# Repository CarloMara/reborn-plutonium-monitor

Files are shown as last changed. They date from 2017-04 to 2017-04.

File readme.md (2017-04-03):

**Introduction**

Reborn Plutoniom Monitor is a small project born from the idea of having the possibility to carry a second monitor around. FYI I'm a student and I move around the city a lot. There are other option in the market that could suit my needs, but they are mostly based off USB, which I imagine would be a pain to get working on linux.

The project is based off a 14 inch laptop display that can be easly found on common on-line stores as spare.

*Things done so far*

I've just designed a first test board with all of the connections from the display's flat cable broken out, so it should be a little easier to test whether or not the pinout of the panel is correct. 

-----------------------------------------------------------------------------------------------------------------------------------------------------------

**Brief Display Info**

The display I have choose it's not very new, but thanks to it's age a datasheet for it is easily repairable.

I've also chosen this display because it's has all the back-lighting control electronic integrated, saving a big hassle. 

----------------------------------------------------------------------------------------------------------------------------------------------------------

**Possible Development Path**

I have bought all the components needed to build the test board , but I still need to find some time to etch a pcb, and try it out.

In the future I plan to make a bigger board, maybe with a 4.0 ble chip in order to control the brightness and get the battery status to the host pc.

Of course this means designing a solution to charge the battery, maybe using USB-PD, but right now I don't have any time for that.

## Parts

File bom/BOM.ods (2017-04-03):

 |  | BOM of Reborn Plutonium Monitor
QTY | PART/PACK | €/PACK | €/PART | URL | INFO | QTY TO BUY | COST | PN – TME | PN- DIGY
1 | 1 | 41 | 41 | http://www.ebay.it/itm/COMPATIBLE-LP140WF1-SP-U1-LCD-LAPTOP-SCREEN-14-0-LG-PHILIPS-PANEL-UK-SHIPP-/380973772351 | LCD panel | 1 | 41
1 | 10 | 6.5 | 0.65 | http://www.ebay.com/itm/10pcs-30-Pin-0-5mm-Pitch-300mm-Power-Ribbon-FFC-Flexible-Flat-Cable-Forward/191950130486 | Flex Ribbon Cable | 1 | 6.5
1 | 1 | 1.59 | 1.59 | http://www.tme.eu/en/details/2040210-1/euro-hdmi-connectors/te-connectivity/ | DP Socket | 1 | 1.59 | 2040210-1
1 | 1 | 0.85 | 0.85 | http://www.tme.eu/en/details/f0500wr-s-30pt/connectors-ffc-fpc-05mm/joint-tech/ | FFC Connector | 1 | 0.85 | F0500WR-S-30PT
1 | 1 | 2.9 | 2.9 | http://www.tme.eu/en/details/mx-98266-0317/ffc-fpc-ribbon-cables/molex/982660317/ | FFC cable | 1 | 2.9 | MX-98266-0317
 |  |  |  |  |  |  |  | TOTAL COST
 |  |  |  |  |  |  |  | € 52.84

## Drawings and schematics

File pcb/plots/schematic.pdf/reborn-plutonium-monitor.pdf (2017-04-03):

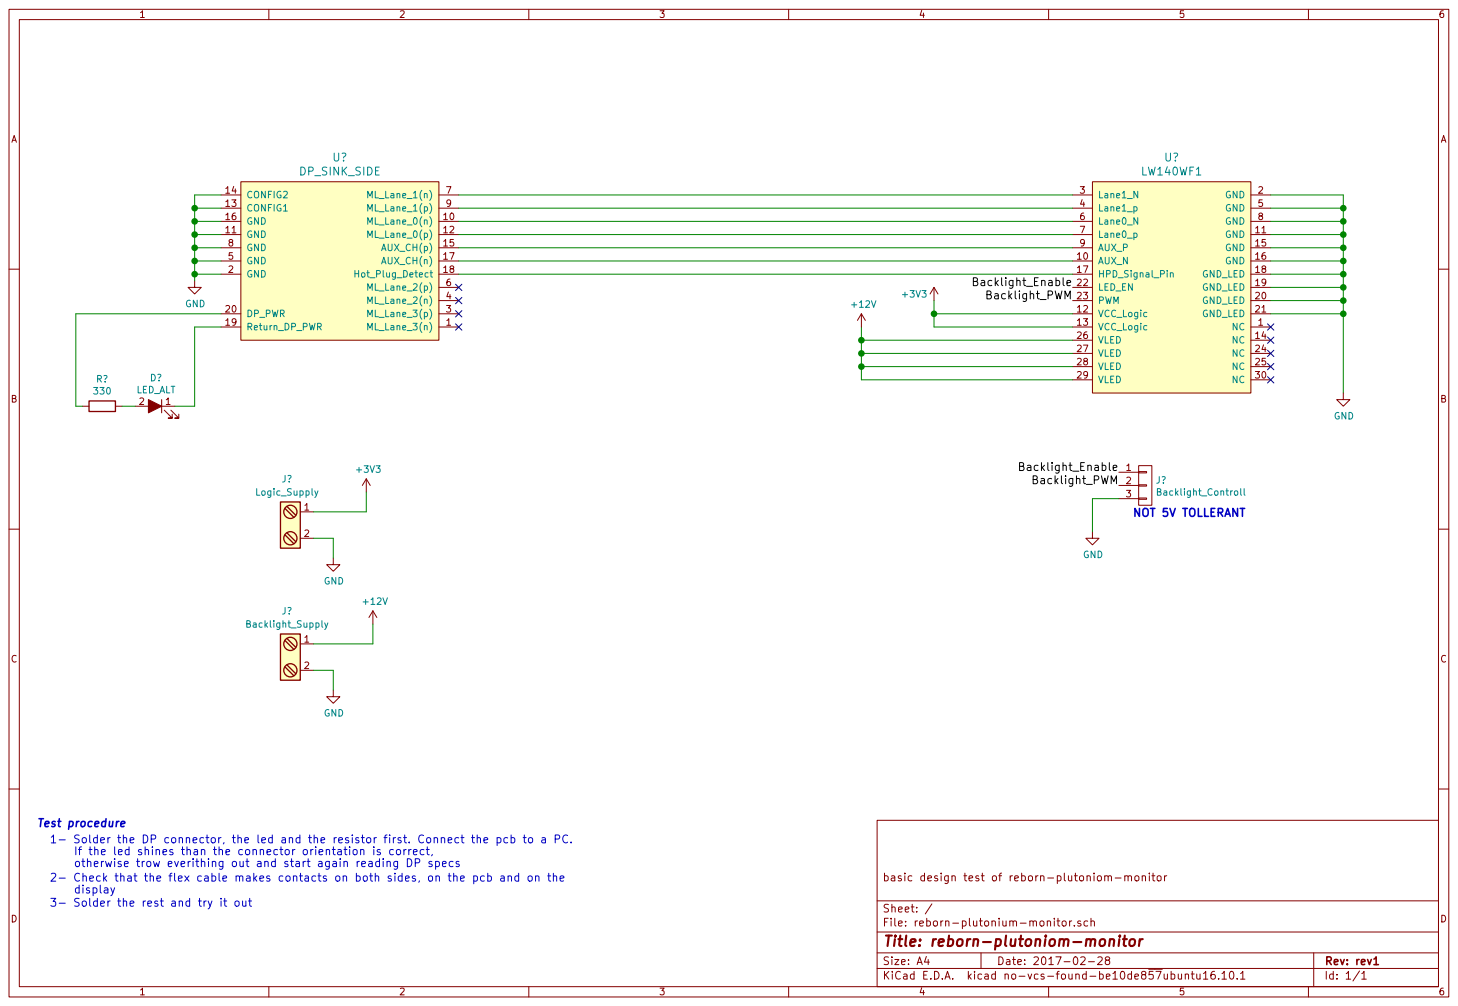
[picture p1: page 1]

1- Solder the DP connector, the led and the resistor first. Connect the pcb to a PC.
If the led shines than the connector orientation is correct,
otherwise trow everithing out and start again reading DP specs
2- Check that the flex cable makes contacts on both sides, on the pcb and on the
display

File: reborn-plutonium-monitor.sch Sheet: / basic design test of reborn-plutoniom-monitor

Id: 1/1 Title: reborn-plutoniom-monitor

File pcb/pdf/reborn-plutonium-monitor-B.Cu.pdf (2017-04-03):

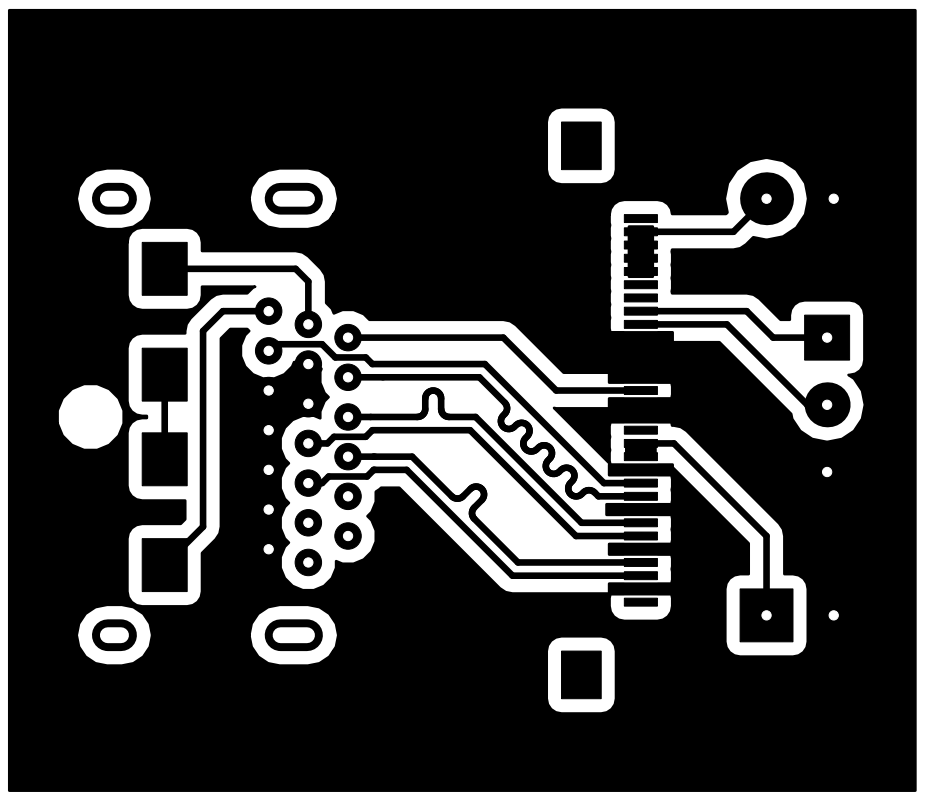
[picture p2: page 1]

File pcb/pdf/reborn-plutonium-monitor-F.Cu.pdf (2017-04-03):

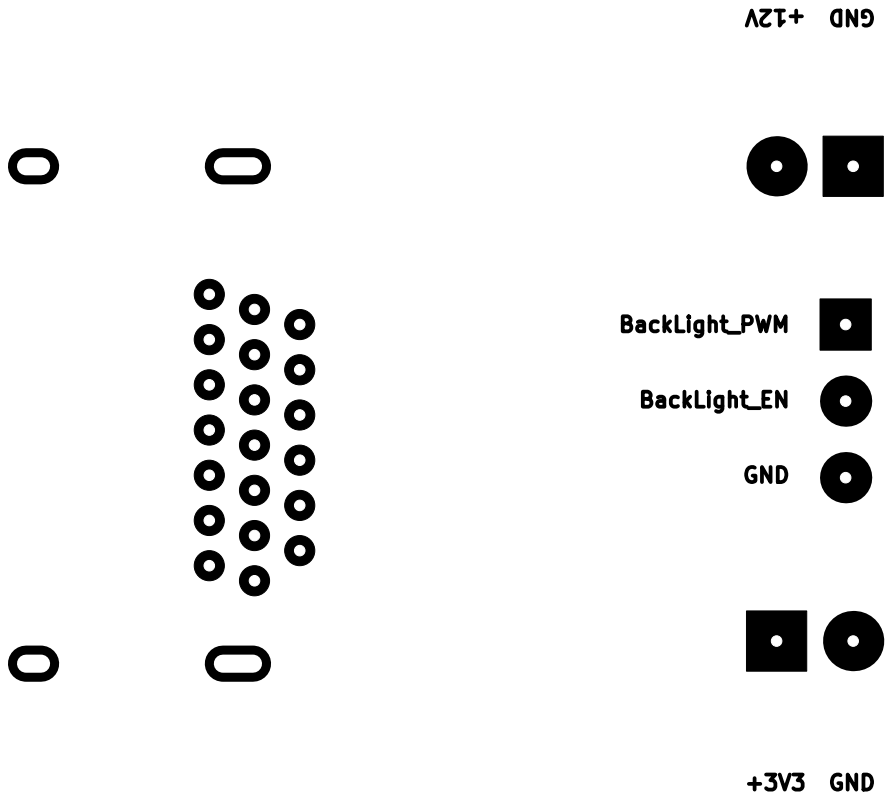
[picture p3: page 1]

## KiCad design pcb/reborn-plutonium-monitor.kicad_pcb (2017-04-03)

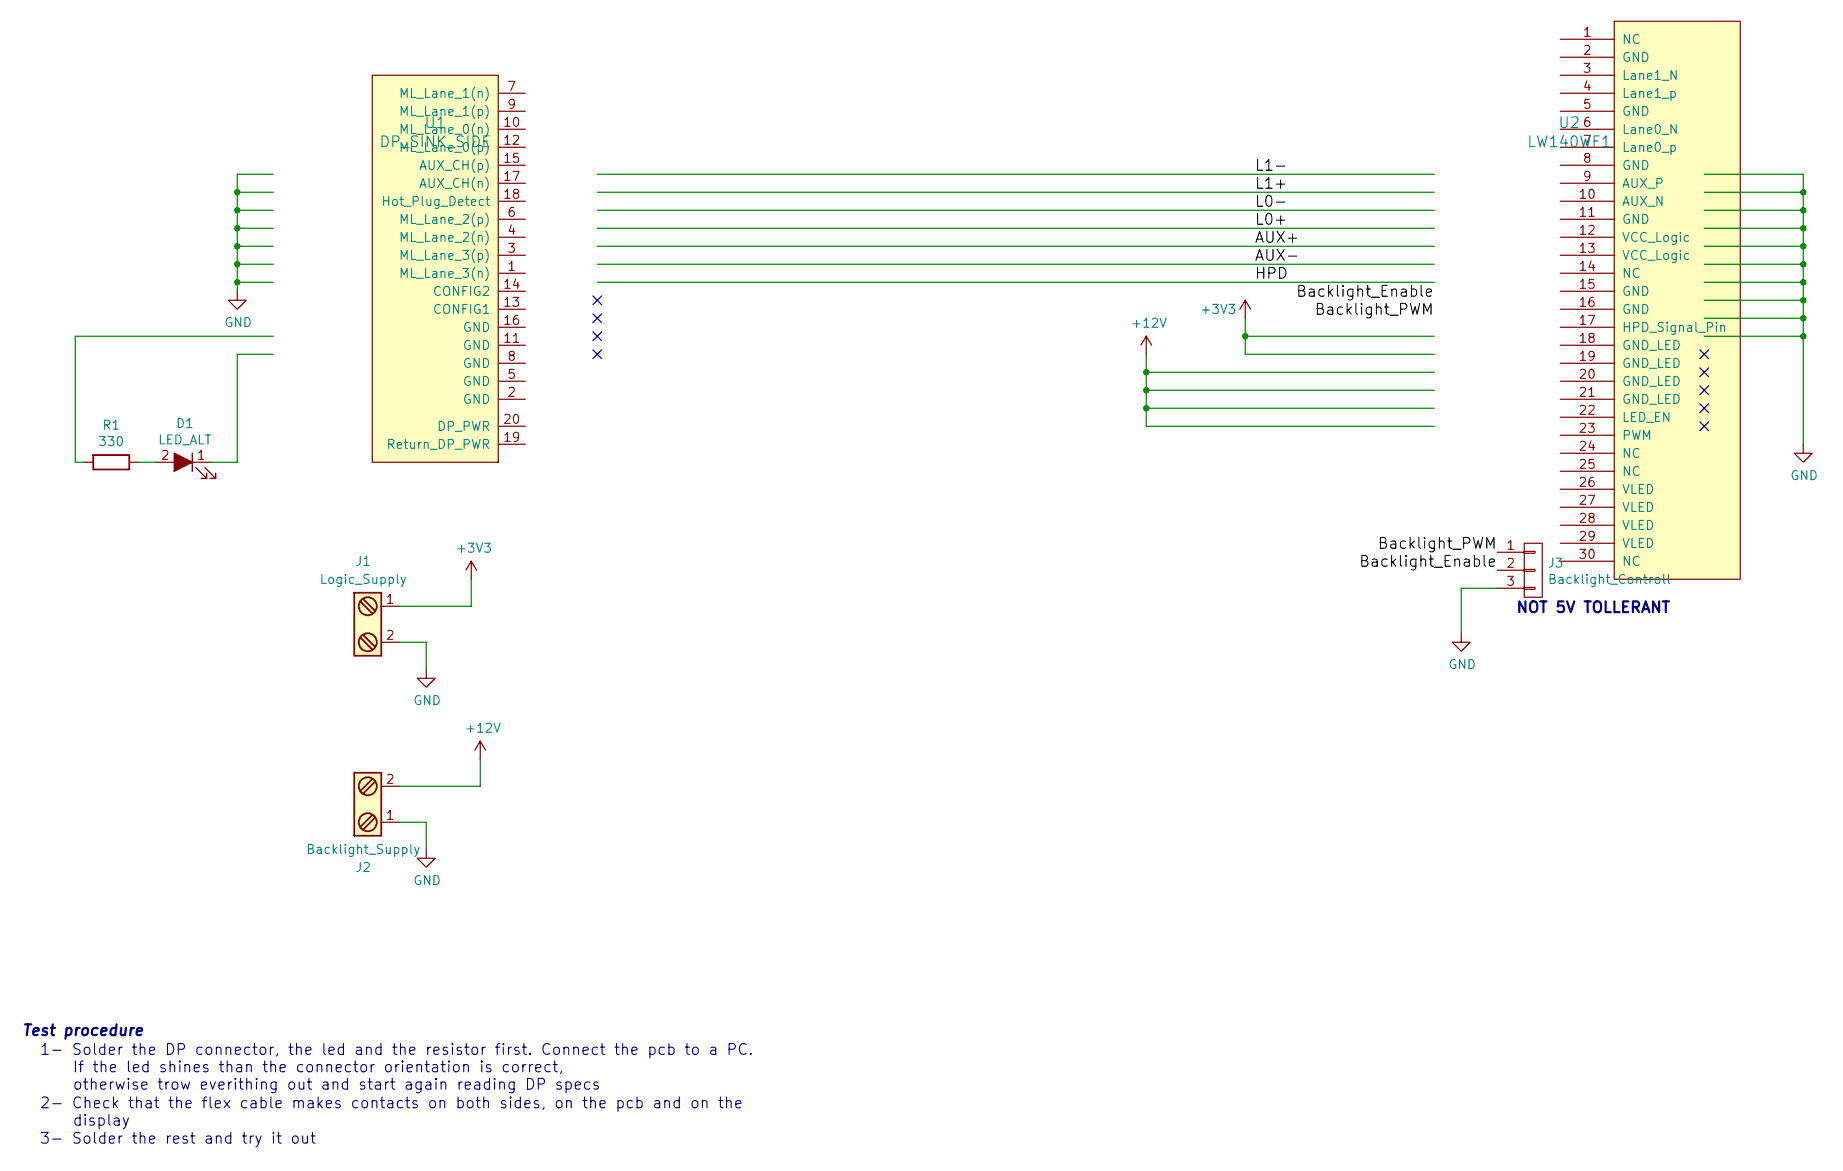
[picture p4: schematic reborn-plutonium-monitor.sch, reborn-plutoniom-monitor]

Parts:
D1: LED_ALT; R_1206_HandSoldering
J1: Logic_Supply; TerminalBlock_Pheonix_MPT-2.54mm_2pol
J2: Backlight_Supply; TerminalBlock_Pheonix_MPT-2.54mm_2pol
J3: Backlight_Controll; Pin_Header_Straight_1x03_Pitch2.54mm
R1: 330; R_1206_HandSoldering
U1: DP_SINK_SIDE; 2040210-1
U2: LW140WF1; F0500WR-S-30PT

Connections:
+3V3: J1.1, U2.12 (VCC_Logic), U2.13 (VCC_Logic)
+12V: J2.2, U2.26 (VLED), U2.27 (VLED), U2.28 (VLED), U2.29 (VLED)
/AUX+: U1.15 (AUX_CH(p)), U2.9 (AUX_P)
/AUX-: U1.17 (AUX_CH(n)), U2.10 (AUX_N)
/Backlight_Enable: J3.2, U2.22 (LED_EN)
/Backlight_PWM: J3.1, U2.23 (PWM)
/HPD: U1.18 (Hot_Plug_Detect), U2.17 (HPD_Signal_Pin)
/L0+: U1.12 (ML_Lane_0(p)), U2.7 (Lane0_p)
/L0-: U1.10 (ML_Lane_0(n)), U2.6 (Lane0_N)
/L1+: U1.9 (ML_Lane_1(p)), U2.4 (Lane1_p)
/L1-: U1.7 (ML_Lane_1(n)), U2.3 (Lane1_N)
GND: J1.2, J2.1, J3.3, U1.2 (GND), U1.5 (GND), U1.8 (GND), U1.11 (GND), U1.13 (CONFIG1), U1.14 (CONFIG2), U1.16 (GND), U2.2 (GND), U2.5 (GND), U2.8 (GND), U2.11 (GND), U2.15 (GND), U2.16 (GND), U2.18 (GND_LED), U2.19 (GND_LED), U2.20 (GND_LED), U2.21 (GND_LED)
unnamed: D1.1 (K), U1.19 (Return_DP_PWR)
unnamed: D1.2 (A), R1.1
unnamed: R1.2, U1.20 (DP_PWR)

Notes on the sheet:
Test procedure
1- Solder the DP connector, the led and the resistor first. Connect the pcb to a PC. If the led shines than the connector orientation is correct, otherwise trow everithing out and start again reading DP specs
2- Check that the flex cable makes contacts on both sides, on the pcb and on the display
3- Solder the rest and try it out
NOT 5V TOLLERANT

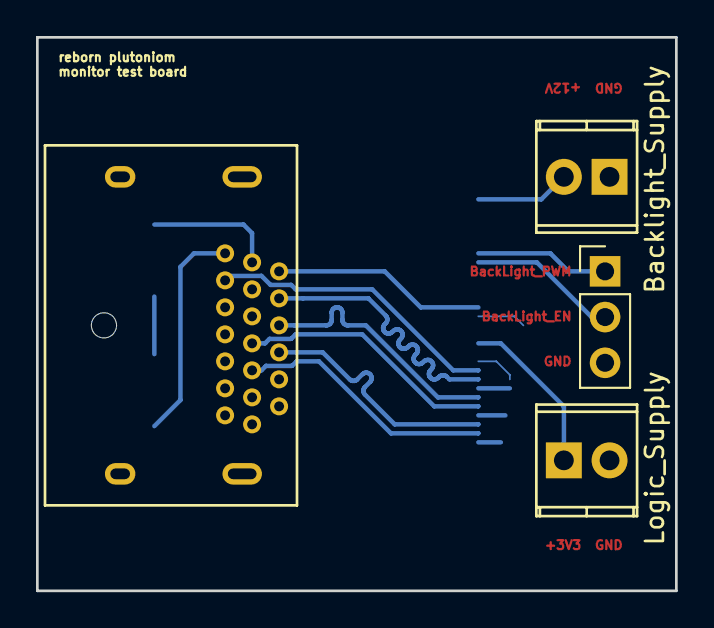
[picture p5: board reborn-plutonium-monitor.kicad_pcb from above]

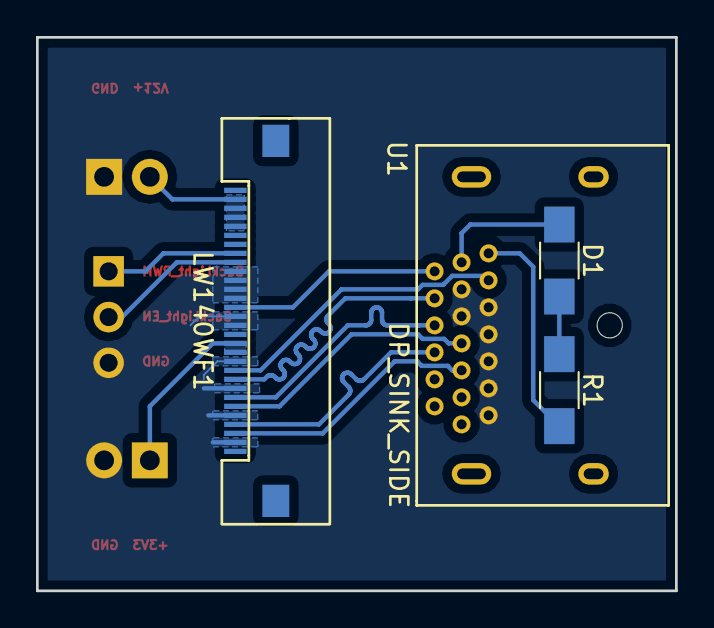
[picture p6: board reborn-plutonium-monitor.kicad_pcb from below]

Board: 2 copper layers, 35.5 x 30.8 mm, 7 parts (3 on the bottom side), 15 nets.

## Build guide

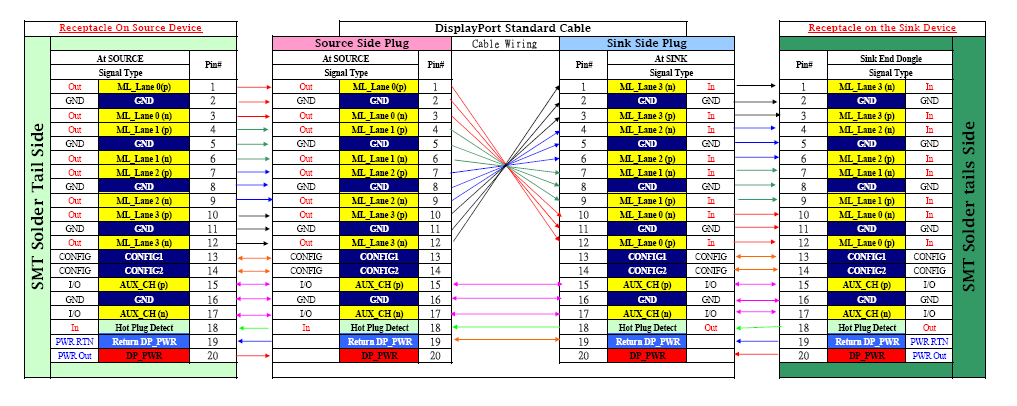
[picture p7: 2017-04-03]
datasheet/DP_WIRING.png
